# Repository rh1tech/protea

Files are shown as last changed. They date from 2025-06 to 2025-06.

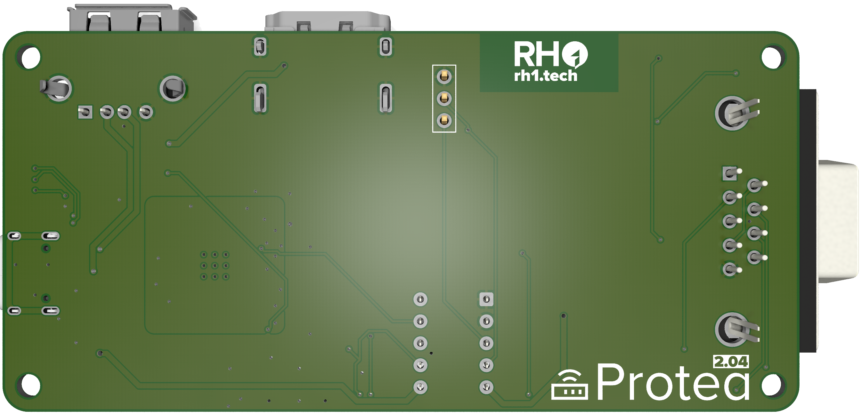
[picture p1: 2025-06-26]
DOCS/back.png

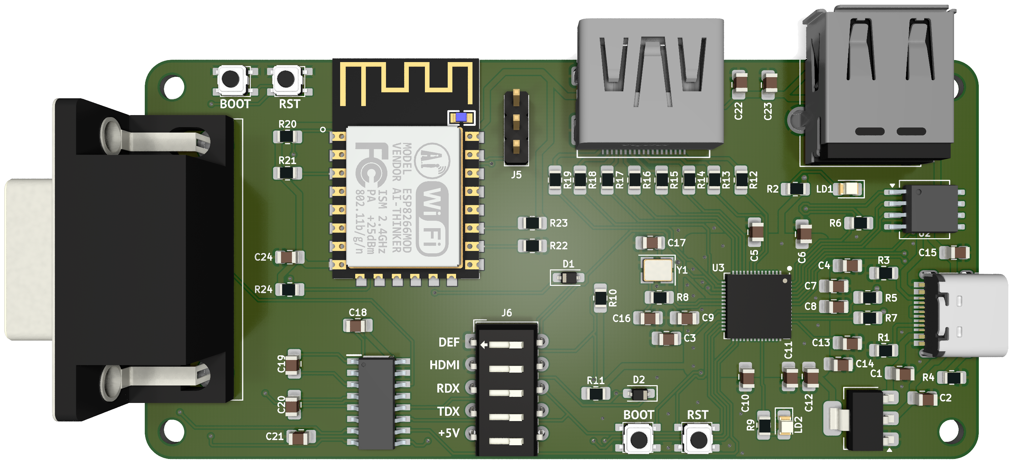
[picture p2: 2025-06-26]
DOCS/front.png

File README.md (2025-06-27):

# Protea

Protea is a custom development board designed in KiCad that bridges the gap between vintage computing and modern connectivity. Named after the protea flower, which itself derives from Proteus, son of Poseidon in Greek mythology, this board embodies the shape-shifting adaptability that made the mythological Proteus legendary. Just as the protea flower has survived and adapted for over 300 million years, becoming a symbol of longevity and endurance, the Protea development board is designed to endure and adapt across different technological eras.

The protea’s incredible diversity of forms - which inspired Carl Linnaeus to name it after the shape-shifting Proteus - mirrors this board’s versatility in connecting vintage computing with modern internet capabilities.

Documentation: [rh1.tech](https://rh1.tech/projects/protea)

## Hardware Specifications

### Primary Controller:

- RP2040 Microcontroller - directly soldered on board
- Dual-core ARM Cortex-M0+ processor running up to 133 MHz
- 264kB on-chip SRAM for program execution
- 8 Programmable I/O (PIO) state machines for custom peripheral support

### Connectivity Controller:
- ESP8266 Microcontroller - integrated Wi-Fi-to-Serial modem functionality
- 802.11 Wi-Fi support for internet connectivity
- AT command compatibility for seamless vintage computer integration

### Interface Ports:

- USB Port - keyboard input support with hub compatibility
- DB9 Serial Port - RS232 connectivity for vintage computers and external devices
- HDMI Port - native digital video output without conversion
- Power Input - USB-powered operation

## Firmware Ecosystem

Protea operates using two complementary firmware components:

### [Iris](https://github.com/rh1tech/iris) Terminal Software

- VT100/VT102 terminal emulation with full attribute support
- Instant-on operation with no boot time
- Configurable fonts and display settings
- PETSCII mode for Commodore compatibility

### [Hermes](https://github.com/rh1tech/hermes) Wi-Fi Modem

- Hayes-compatible AT command set
- Telnet protocol support for internet connectivity
- Transparent Wi-Fi-to-Serial bridge operation
- BBS and vintage online service access

## Use Cases

Protea enables seamless connection of classic computers to modern internet resources, providing access to text-mode BBS systems and online communities that maintain the spirit of early computing culture. The board serves as a bridge between RS232 devices and Wi-Fi networks, ensuring that vintage computing enthusiasts can maintain an authentic retro computing experience while leveraging contemporary internet connectivity.

The platform supports text-mode internet browsing for those who prefer minimalist computing approaches, while also serving as a foundation for terminal-based development environments. Protea is particularly well-suited for retrocomputing projects that require modern connectivity solutions, and functions as an educational platform for understanding the fundamentals of serial communications and terminal operations.

## Design Philosophy

Like the protea flower that has endured and adapted for over 300 million years, and the shape-shifting Proteus of Greek mythology, this development board embodies longevity, adaptability, and transformation. The board’s dual-microcontroller architecture ensures optimal performance for both local terminal processing and network communications, demonstrating the same versatility that characterizes its mythological and botanical namesakes.

The custom PCB design prioritizes signal integrity and reliable connectivity, making it suitable for both hobbyist projects and professional applications requiring robust serial terminal functionality.

## Getting Started

1.	Flash Firmware - Load [Iris](https://github.com/rh1tech/iris) onto the RP2040 and [Hermes](https://github.com/rh1tech/hermes) onto the ESP8266
2.	Connect Display - Attach HDMI monitor for terminal output
3.	Add Keyboard - Connect USB keyboard for input
4.	Configure Wi-Fi - Set up wireless connectivity through Hermes
5.	Connect Devices - Use DB9 port for vintage computer or RS232 device connections

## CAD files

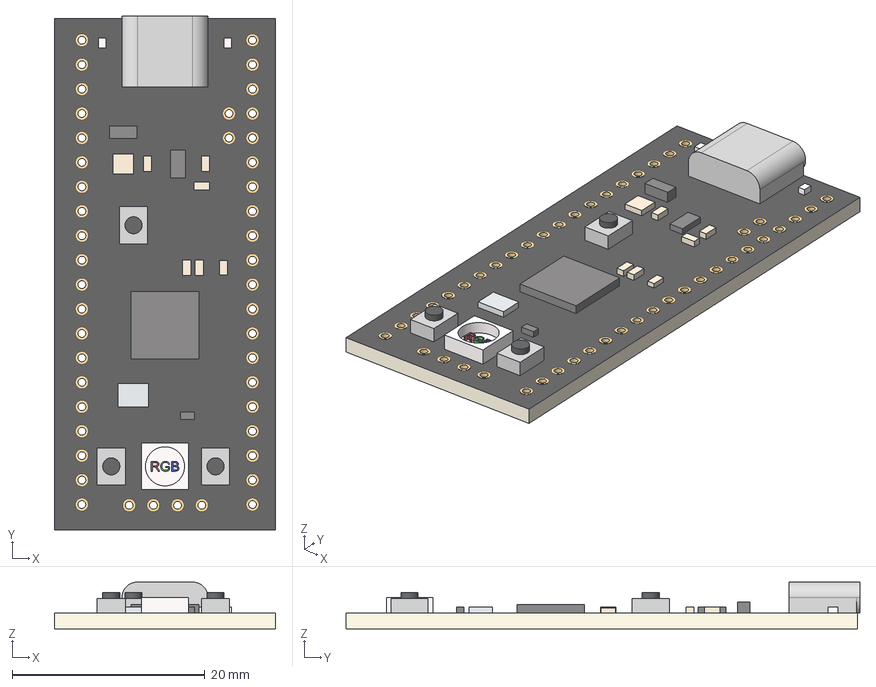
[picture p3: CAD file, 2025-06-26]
3D/PICO Clone-Black .step
22.9 x 53.3 x 4.88 mm

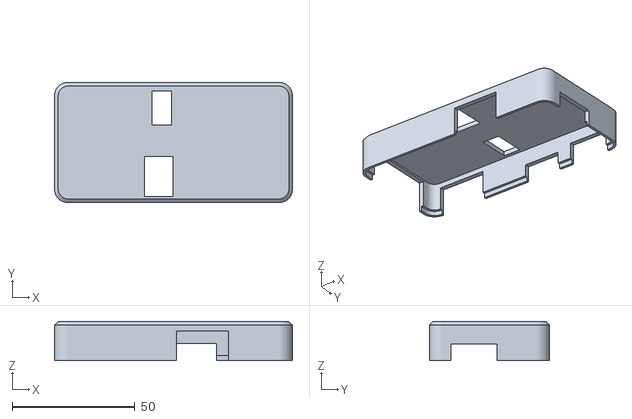
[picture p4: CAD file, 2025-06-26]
CASE/2_04/top.stl
97.0 x 49.0 x 16.0

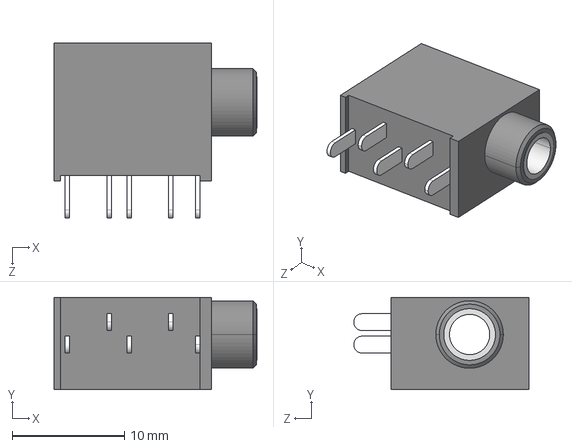
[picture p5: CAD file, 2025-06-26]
3D/SJ1-3535NG.stp
18.1 x 8.20 x 15.6 mm

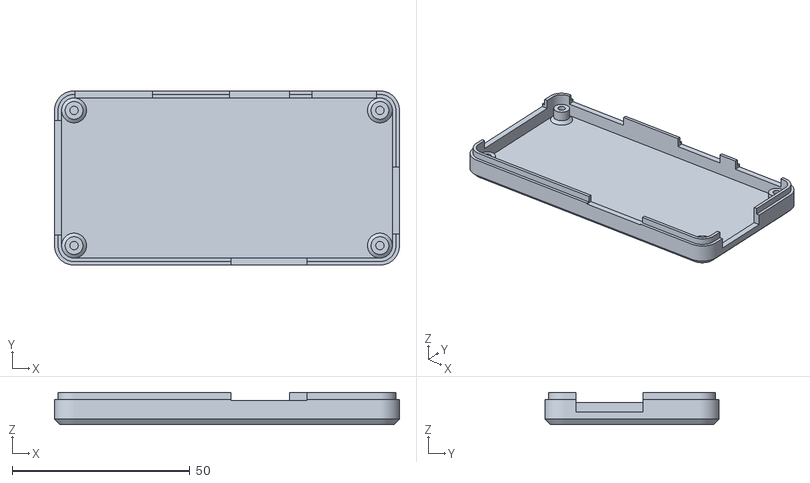
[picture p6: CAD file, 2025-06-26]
CASE/2_04/bottom.stl
97.0 x 49.0 x 9.00

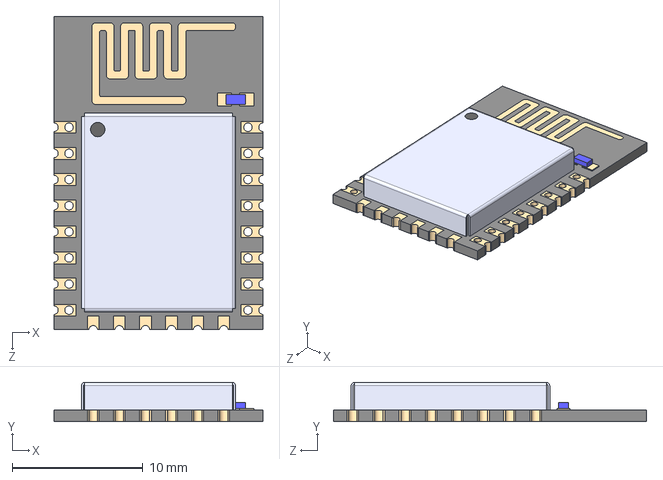
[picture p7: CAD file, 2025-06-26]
3D/ESP8266-12E_ESP-12E.step
16.0 x 3.00 x 24.0 mm

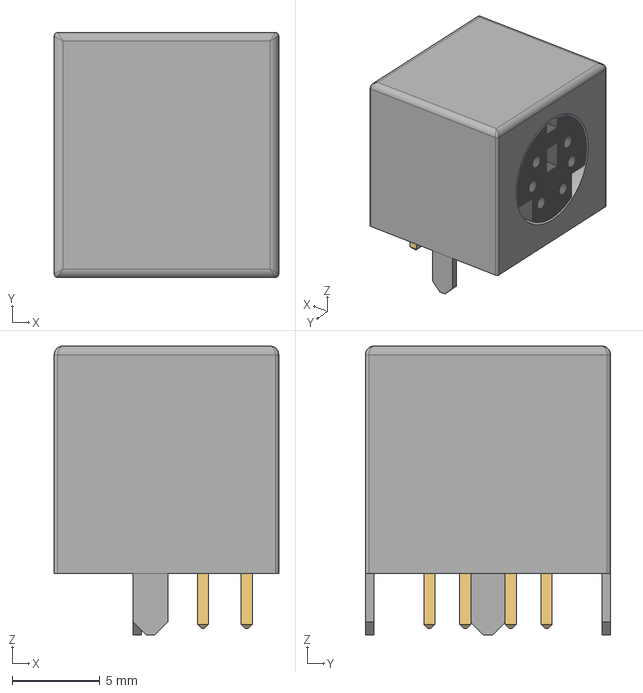
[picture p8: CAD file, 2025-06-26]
3D/Mini-DIN-6P.step
12.8 x 14.0 x 16.5 mm

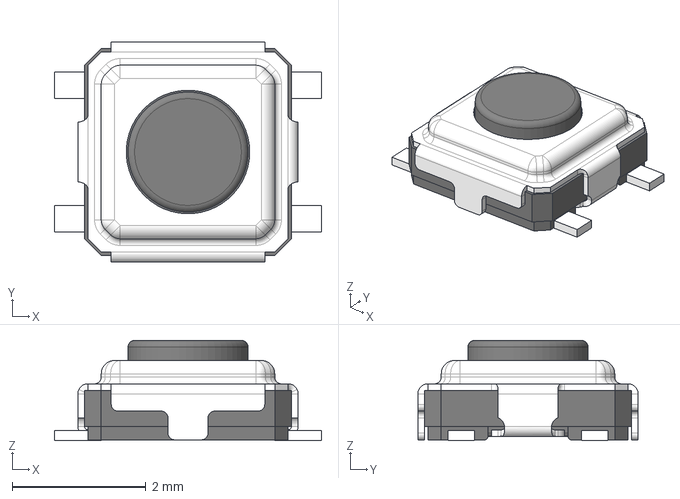
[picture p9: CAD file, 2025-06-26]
3D/Ts-1233_1.5.stp
4.00 x 3.30 x 1.50 mm

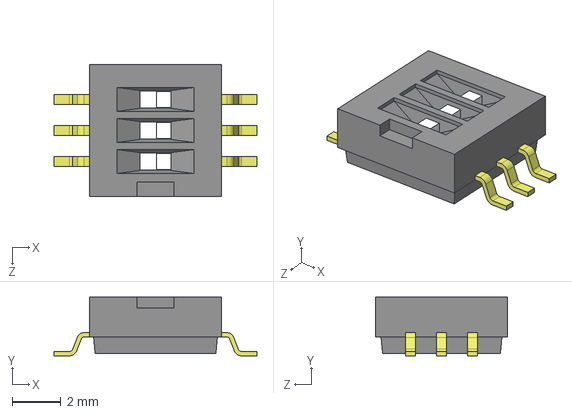
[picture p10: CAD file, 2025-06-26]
3D/DS05-127-2-03BK-SMT-TR.stp
8.30 x 2.40 x 5.38 mm

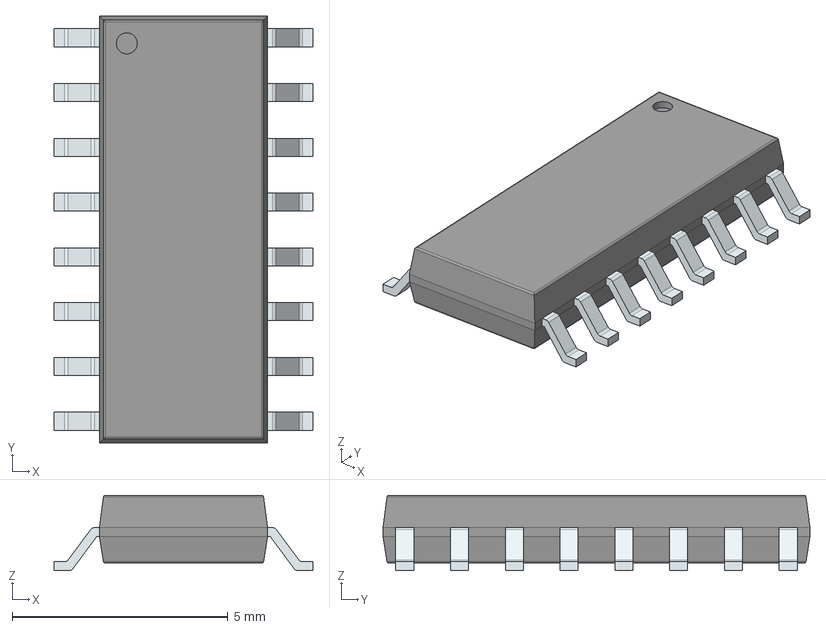
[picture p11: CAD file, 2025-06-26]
3D/MAX232CSE+.stp
6.00 x 9.90 x 1.75 mm
PinsArrayLR

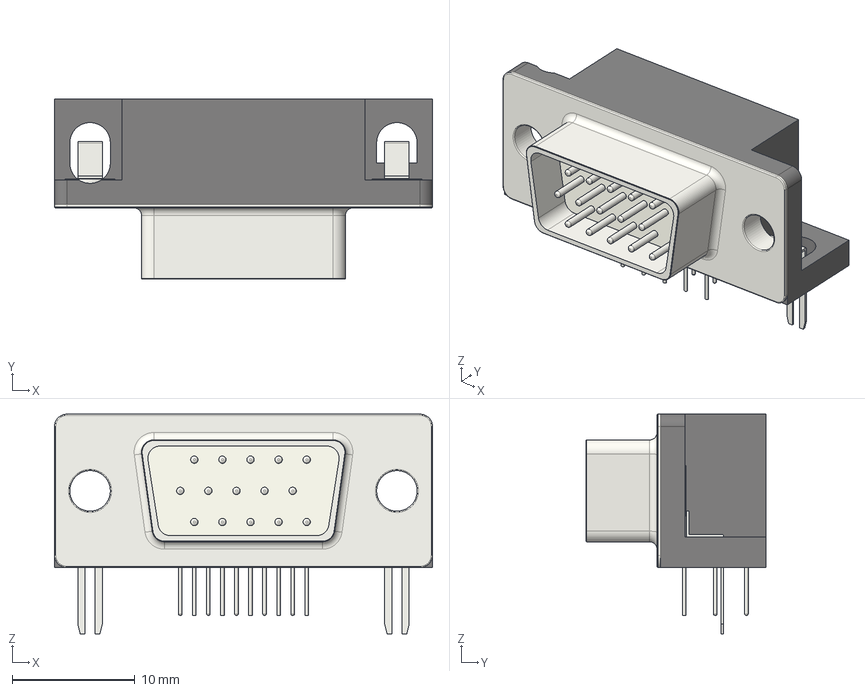
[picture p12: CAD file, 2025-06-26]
3D/DSUB-15-HD_Male_Horizontal_P2.29x1.98mm_EdgePinOffset3.03mm_Housed_MountingHolesOffset4.94mm.step
30.8 x 14.7 x 17.9 mm

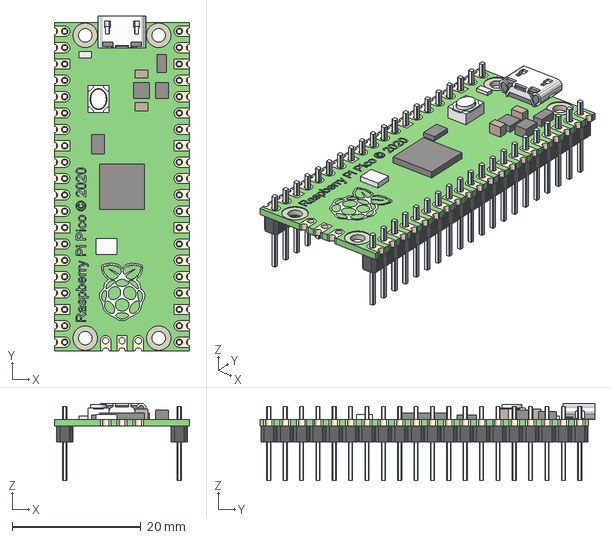
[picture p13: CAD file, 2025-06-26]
3D/raspberry pi pico with contacts.step
21.0 x 52.0 x 12.0 mm
ножка x 20
ножка v3(Mirror) x 20

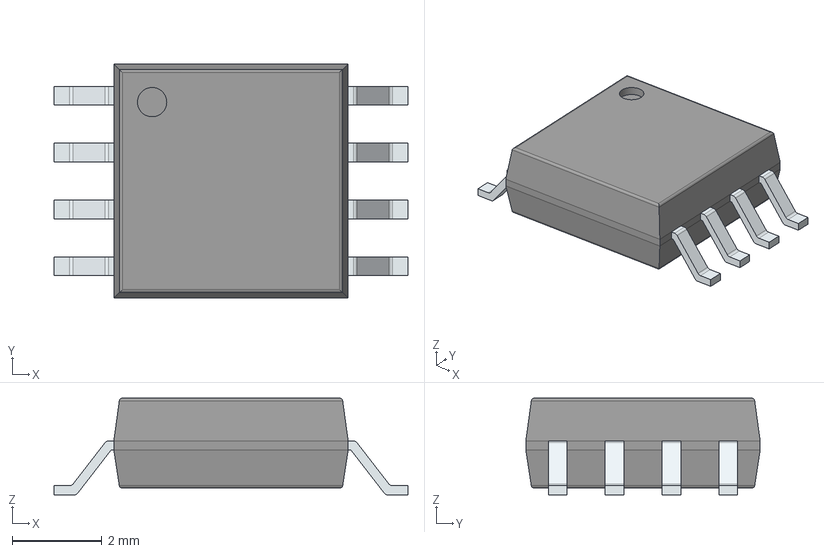
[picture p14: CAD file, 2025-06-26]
3D/W25Q128JVSIQ.stp
7.90 x 5.23 x 2.16 mm
PinsArrayLR

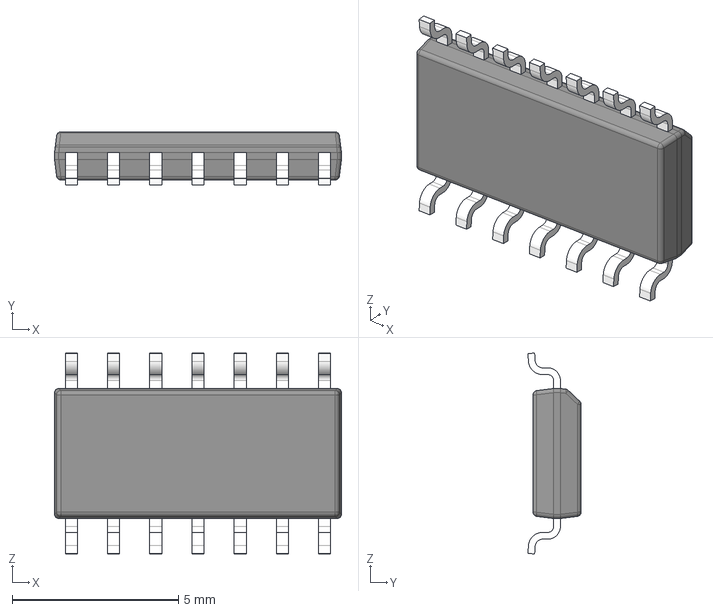
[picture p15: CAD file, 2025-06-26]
3D/soic-14.stp
8.64 x 1.60 x 6.05 mm
BODY_M14A_20
LEAD_M14A_46 x 14

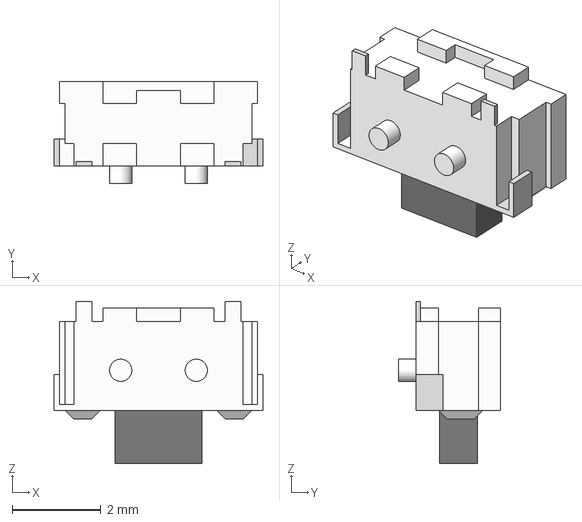
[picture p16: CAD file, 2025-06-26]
3D/1TS003B.step
4.70 x 2.30 x 3.65 mm

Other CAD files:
3D/PJ320D.STEP
3D/DSUB-9_Female_Horizontal_P2.77x2.84mm_EdgePinOffset9.90mm_Housed_MountingHolesOffset11.32mm.step
3D/SO-8_5.3x6.2mm_P1.27mm.step
3D/TS3USB221RSER.stp
3D/47571-0001.stp
3D/CUI_DEVICES_RCJ-013.step
3D/HRO_TYPE-C-31-M-12.step
3D/USB1035-GF-P-0-B-B.stp

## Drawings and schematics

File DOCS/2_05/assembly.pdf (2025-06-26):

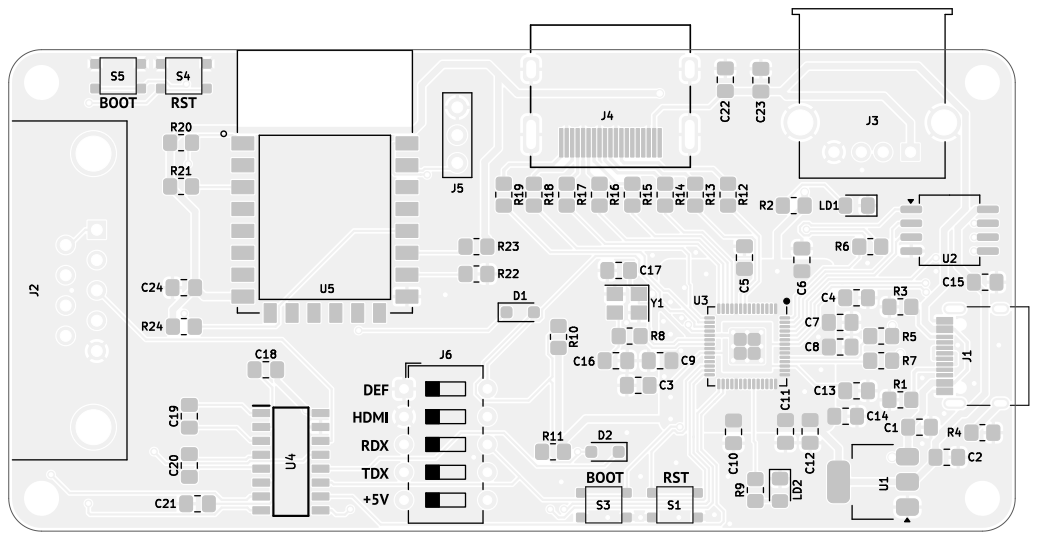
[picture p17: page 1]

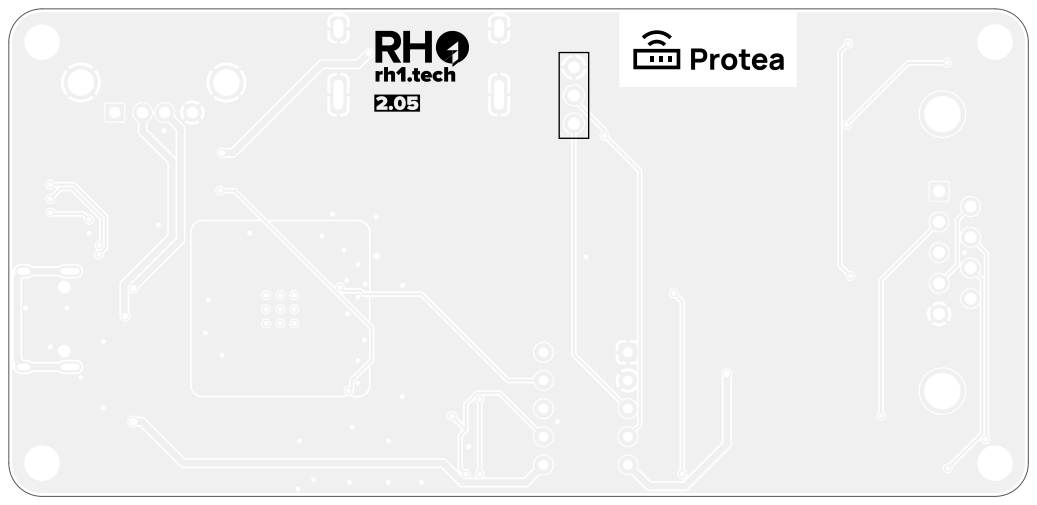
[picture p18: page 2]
D Date: 2025-04-21 KiCad; E.D.A. 9.0.0 Size: A4; Rev: 2.05; File: protea.kicad_pcb Sheet: Black; And; White; BOT Mikhail; Matveev; https://github.com/xtremespb/frank Black; BOT -; Page 2/4

Id: /1 Title: Protea

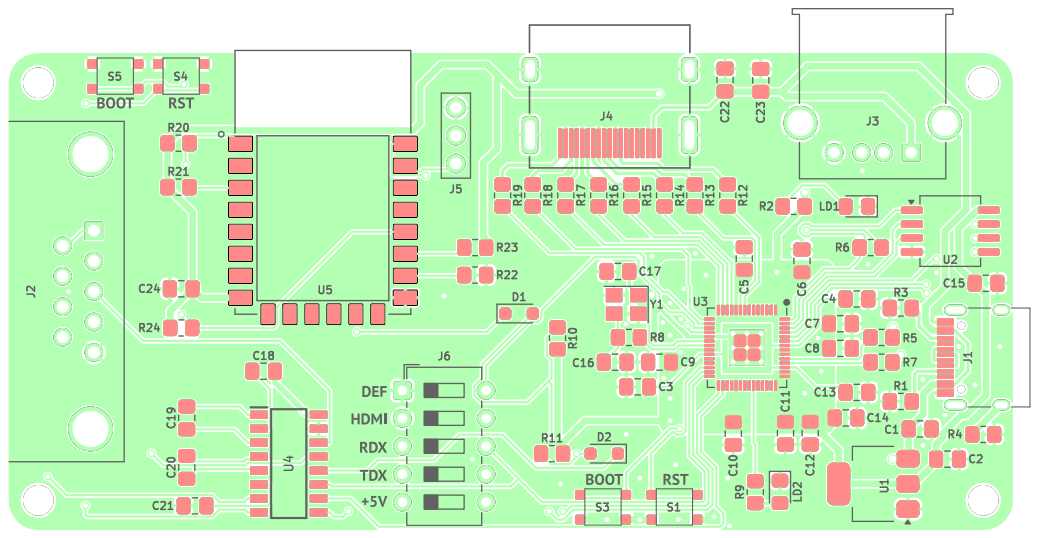
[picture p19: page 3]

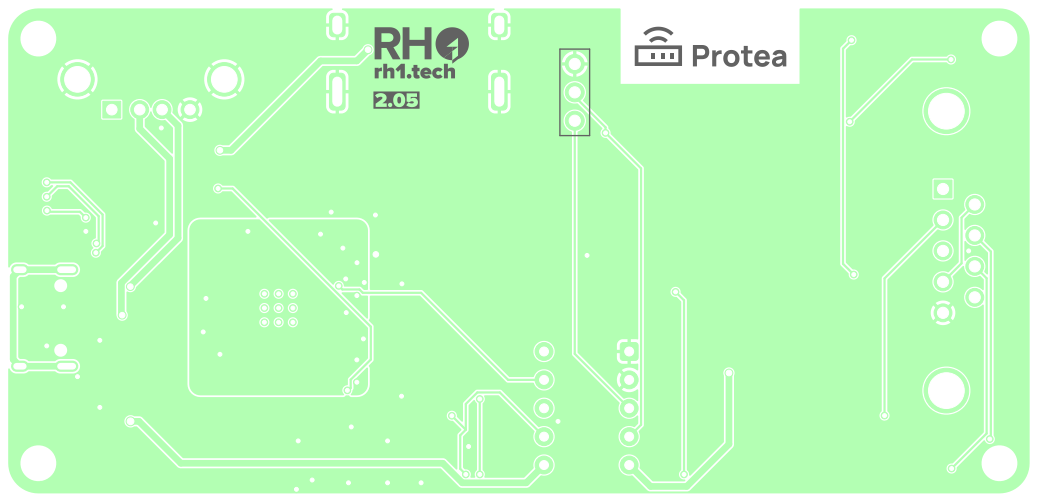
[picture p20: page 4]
D Date: 2025-04-21 KiCad; E.D.A. 9.0.0 Size: A4; Rev: 2.05; File: protea.kicad_pcb Sheet: Colored; BOT Mikhail; Matveev; https://github.com/xtremespb/frank Colored; BOT -; Page 4/4

Id: /1 Title: Protea

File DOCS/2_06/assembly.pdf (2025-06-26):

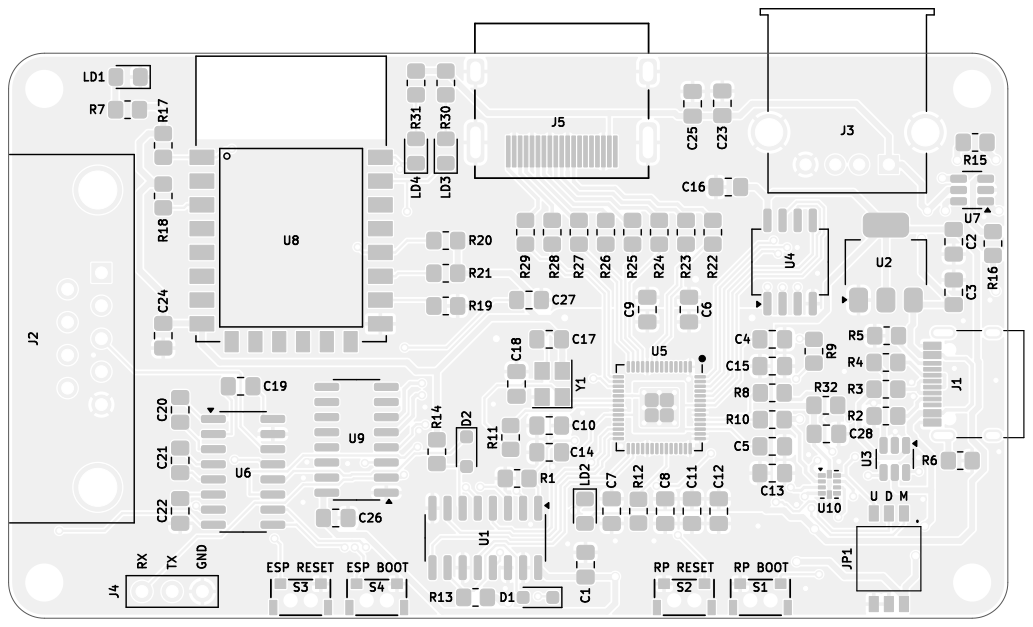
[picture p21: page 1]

https://github.com/xtremespb/frank Black And White TOP - Page 1/4

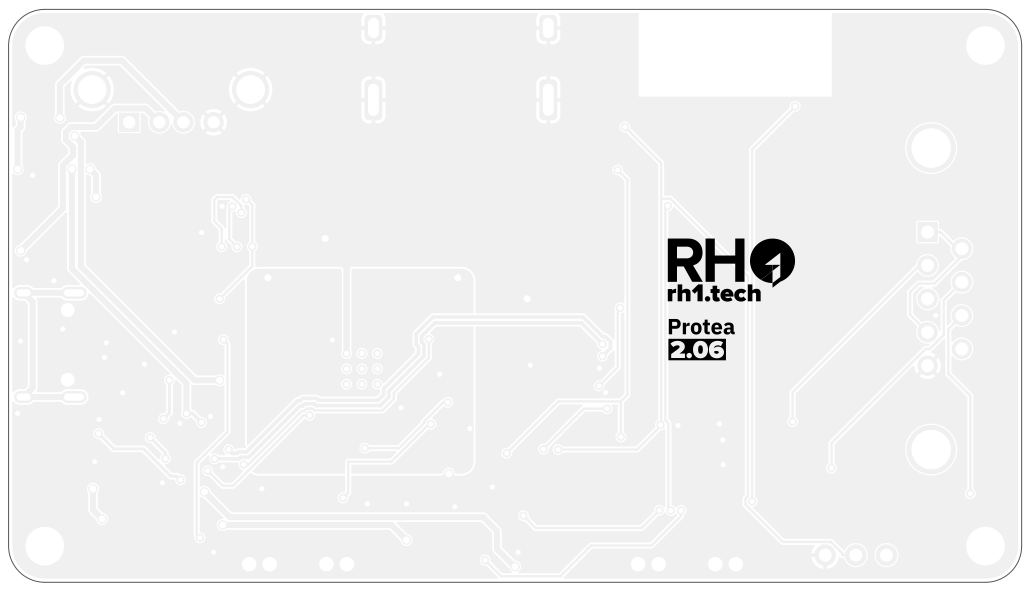
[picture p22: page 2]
D Date: 2025-04-21 KiCad; E.D.A. 9.0.0 Size: A4; Rev: 2.06; File: protea.kicad_pcb Sheet: Black; And; White; BOT Mikhail; Matveev; https://github.com/xtremespb/frank Black; BOT -; Page 2/4

Id: /1 Title: Protea

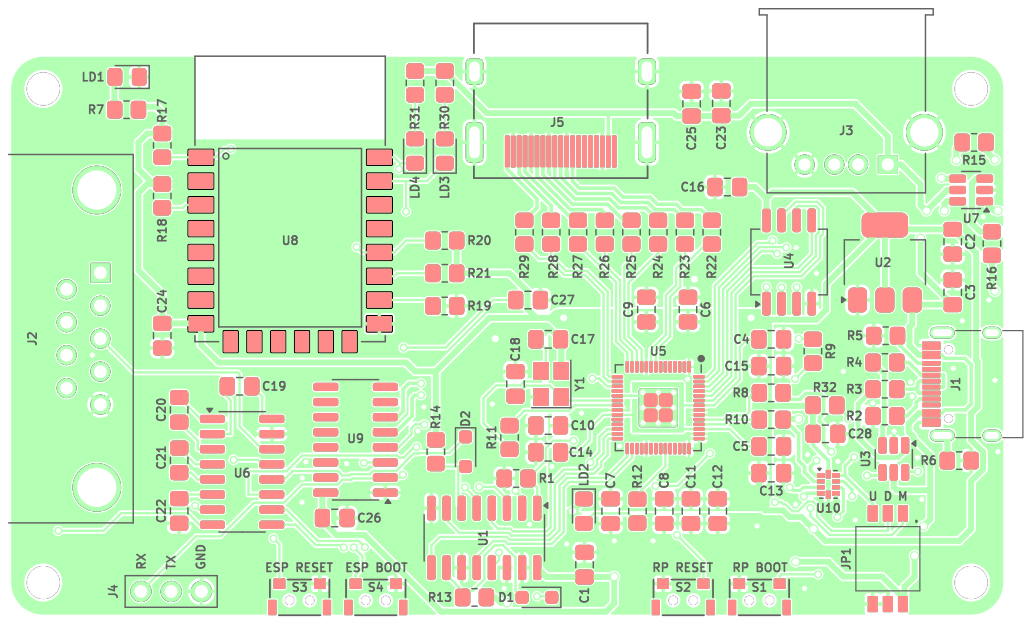
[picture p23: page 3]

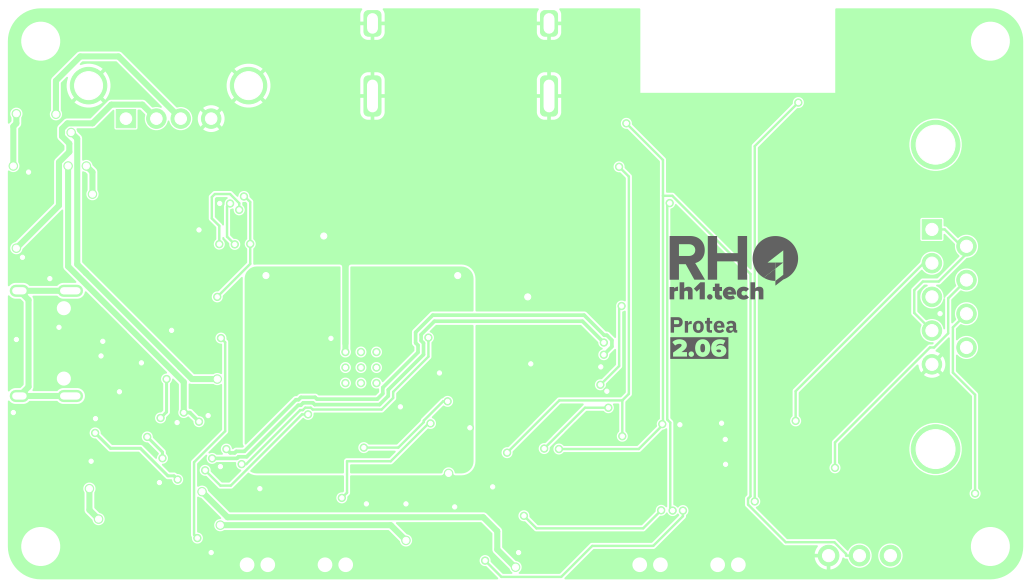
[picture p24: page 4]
D Date: 2025-04-21 KiCad; E.D.A. 9.0.0 Size: A4; Rev: 2.06; File: protea.kicad_pcb Sheet: Colored; BOT Mikhail; Matveev; https://github.com/xtremespb/frank Colored; BOT -; Page 4/4

Id: /1 Title: Protea

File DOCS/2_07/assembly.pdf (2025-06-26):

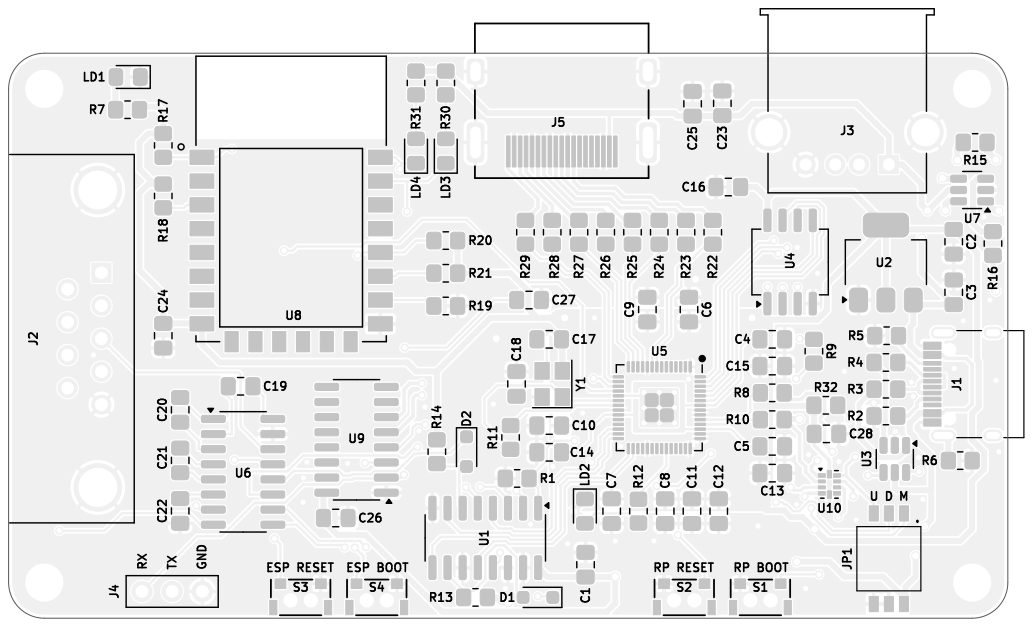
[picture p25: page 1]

https://github.com/xtremespb/frank Black And White TOP - Page 1/4

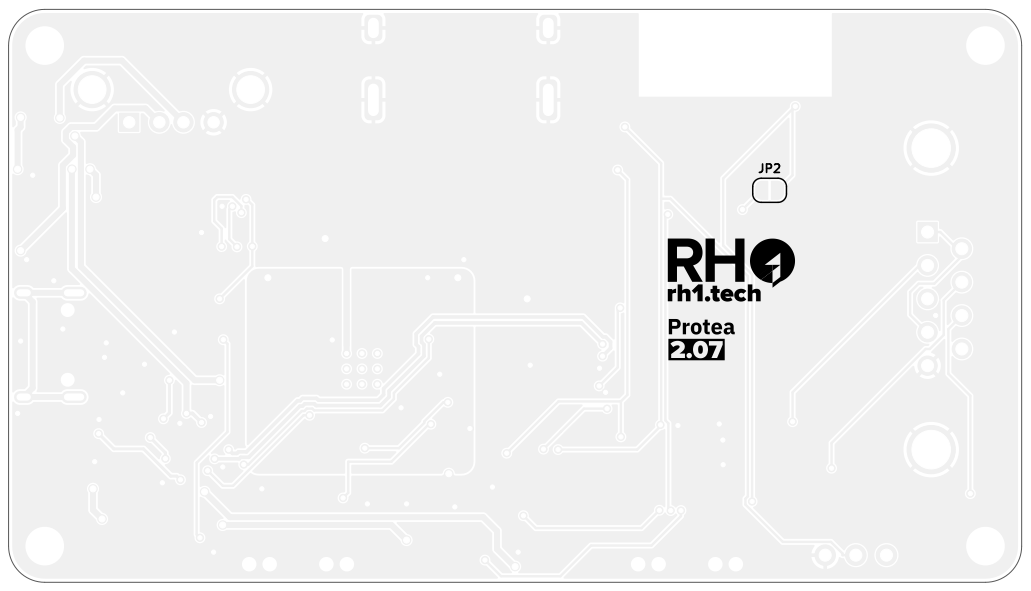
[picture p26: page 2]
D Date: 2025-06-22 KiCad; E.D.A. 9.0.0 Size: A4; Rev: 2.07; File: protea.kicad_pcb Sheet: Black; And; White; BOT Mikhail; Matveev; https://github.com/xtremespb/frank Black; BOT -; Page 2/4

Id: /1 Title: Protea

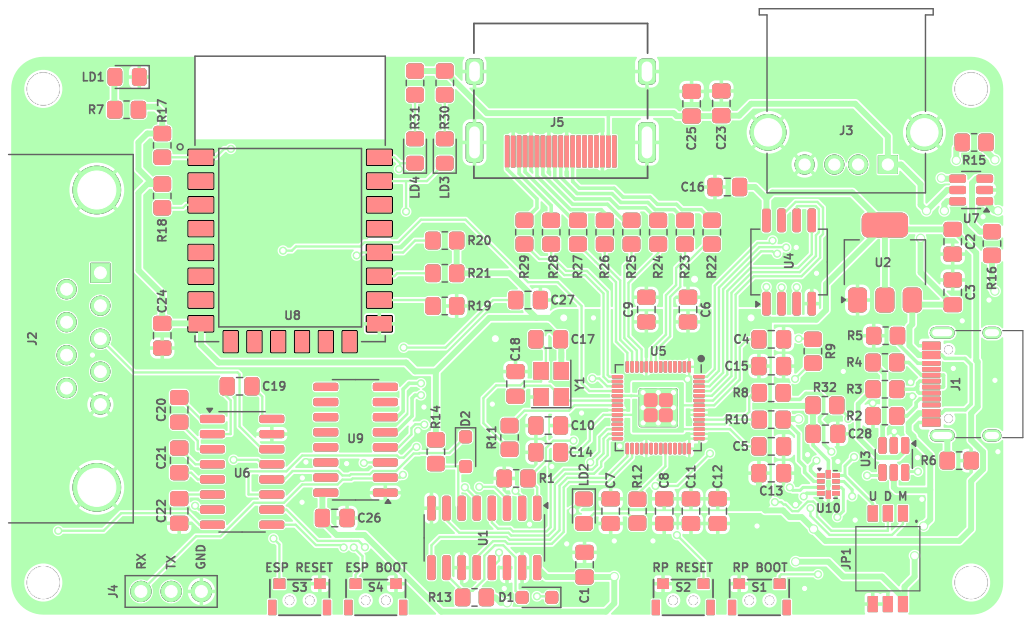
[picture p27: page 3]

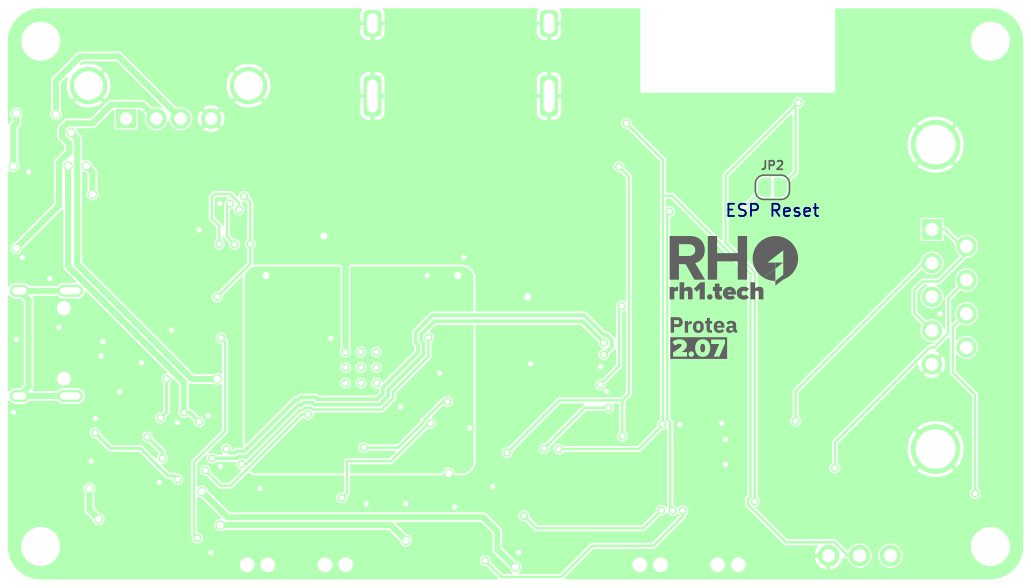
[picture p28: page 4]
D Date: 2025-06-22 KiCad; E.D.A. 9.0.0 Size: A4; Rev: 2.07; File: protea.kicad_pcb Sheet: Colored; BOT Mikhail; Matveev; https://github.com/xtremespb/frank Colored; BOT -; Page 4/4; ESP Reset

Id: /1 Title: Protea

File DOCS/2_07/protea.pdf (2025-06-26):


VBUS GND GND GND

ESP_CSO
GPIO4 GPIO5 GPIO9 GPIO10 GPIO12 GPIO13 GPIO14 GPIO16 MISO MOSI SCLK RXD


https://github.com/xtremespb/frank


4 U4 W25Q128JVSIQGND GND
~{CS} 1 CLK 6 DI(IO0) 5 DO(IO1) 2

https://github.com/xtremespb/frank


https://github.com/xtremespb/frank C20


https://github.com/xtremespb/frank


https://github.com/xtremespb/frank




https://github.com/xtremespb/frank GND

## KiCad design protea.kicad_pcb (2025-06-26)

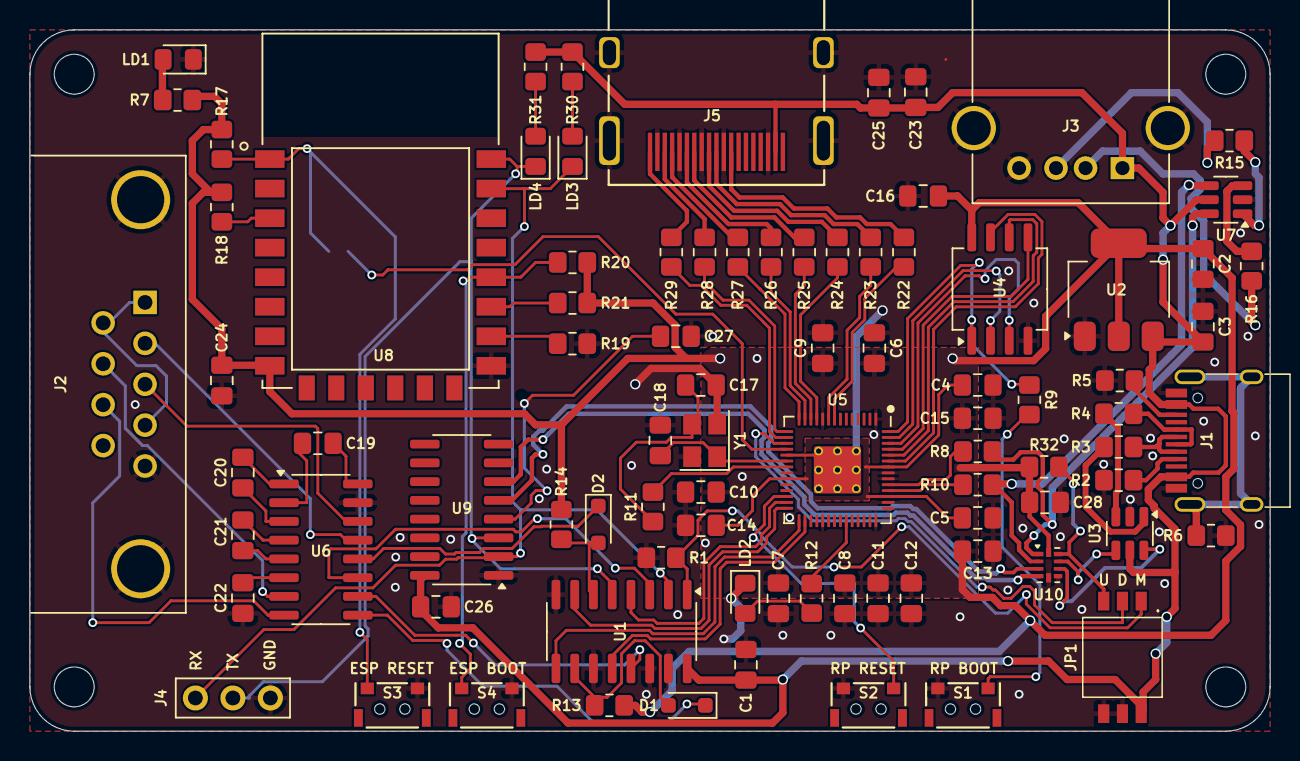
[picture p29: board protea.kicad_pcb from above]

Board: 2 copper layers, 84.0 x 47.5 mm, 92 parts (1 on the bottom side), 89 nets.

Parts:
C1, C4, C5, C6, C7, C8, C9, C10, C11, C12, C13, C16, C25, C26, C27, C28: 100n; Capacitor (0805)
C2, C3, C23: 10u; Capacitor (0805)
C14, C15, C19, C20, C21, C22, C24: 1u; Capacitor (0805)
C17, C18: 15p; Capacitor (0805)
D1, D2: 1N4148; Diode (SOD-323)
H1, H2, H3, H4: MountingHole; Mounting Hole (2.7mm)
J1: USB4215-03-A; USB Type C
J2: D-SUB 9 Male; D-SUB (9 pin, male, top mount)
J3: 676430910; USB Type A (single)
J4: ESP8266 Prog; Pin Header (1x03)
J5: HDMI Female; HDMI (female)
JP1: DS05-127-2-03BK-SMT-TR; DS05127203BKSMTTR
JP2: ESP Reset; Jumper (solder)
LD1: Green; LED (0805)
LD2: Blue; LED (0805)
LD3, LD4: Orange; LED (0805)
R1, R17, R18, R19, R20, R21, R32: 10K; Resistor (0805)
R2, R5: 5.1K; Resistor (0805)
R3, R4, R15, R16: 22R; Resistor (0805)
R6: 1M; Resistor (0805)
R7, R9, R11, R12, R13, R14: 1K; Resistor (0805)
R8, R10: 27R; Resistor (0805)
R22, R23, R24, R25, R26, R27, R28, R29: 270R; Resistor (0805)
R30, R31: 1.5K; Resistor (0805)
S1: Boot; TACT-SIDE-4623
S2, S3: Reset; TACT-SIDE-4623
S4: Flash; TACT-SIDE-4623
U1: SN74CBT3257CDR; SOP-16
U2: NCP1117 3.3; SOT-223
U3, U7: USBLC6-2SC6; SOT-23-6
U4: W25Q128JVSIQ; SOIC-8
U5: RP2040; QFN 56
U6: MAX232CSE+; SOP-16
U8: ESP8266 ESP-12F; ESP8266 ESP-12E
U9: CH340C; SOP-16
U10: TS3USB221RSER; UQFN-10
Y1: 12 MHz Passive; Crystal (3225)

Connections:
+3V3: C2.1, C6.1, C7.1, C8.1, C9.1, C10.1, C11.1, C12.1, C13.1, C15.1, C16.1, C24.1, C28.2, R7.2, R13.2, R14.2, R17.1, R18.1, R20.1, R21.1, R32.1, U2.2 (VO), U4.8 (VCC), U5.1 (IOVDD), U5.10 (IOVDD), U5.22 (IOVDD), U5.33 (IOVDD), U5.42 (IOVDD), U5.43 (ADC_AVDD), U5.44 (VREG_IN), U5.48 (USB_VDD), U5.49 (IOVDD), U8.8 (VCC), U10.10 (VCC)
/ESP_RESET: JP2.2 (B), R17.2, S3.2, U8.1 (RESET)
/ESP_RXD: J4.1, LD3.1 (K), U1.2 (1B1), U8.21 (RXD), U9.2 (TxD)
/ESP_TXD: J4.2, LD4.1 (K), U1.5 (2B1), U8.22 (TXD), U9.3 (RxD)
/GPIO6: R22.2, U5.8 (GPIO6)
/GPIO7: R23.2, U5.9 (GPIO7)
/GPIO8: R24.2, U5.11 (GPIO8)
/GPIO9: R25.2, U5.12 (GPIO9)
/GPIO10: R26.2, U5.13 (GPIO10)
/GPIO11: R27.2, U5.14 (GPIO11)
/GPIO12: R28.2, U5.15 (GPIO12)
/GPIO13: R29.2, U5.16 (GPIO13)
/GPIO14: JP1.2, U5.17 (GPIO14)
/GPIO15: JP2.1 (A), U5.18 (GPIO15)
/GPIO16: U1.4 (1A), U5.27 (GPIO16)
/GPIO17: U1.7 (2A), U5.28 (GPIO17)
/GPIO18: U1.9 (3A), U5.29 (GPIO18)
/GPIO19: U1.12 (4A), U5.30 (GPIO19)
/PW_D+: U3.4 (I/O2), U10.8 (D+)
/PW_D-: U3.6 (I/O1), U10.7 (D-)
/RP2040/GPIO25: R12.2, U5.37 (GPIO25)
/RP2040/QSPI_SCLK: U4.6 (CLK), U5.52 (QSPI_SCLK)
/RP2040/QSPI_SD0: U4.5 (DI(IO0)), U5.53 (QSPI_SD0)
/RP2040/QSPI_SD1: U4.2 (DO(IO1)), U5.55 (QSPI_SD1)
/RP2040/QSPI_SD2: U4.3 (IO2), U5.54 (QSPI_SD2)
/RP2040/QSPI_SD3: U4.7 (IO3), U5.51 (QSPI_SD3)
/RP2040/QSPI_SS: R9.1, U4.1 (~CS), U5.56 (QSPI_SS)
/RP2040/XIN: C18.1, U5.20 (XIN), Y1.1
/RP2040/XOUT: R11.1, U5.21 (XOUT)
/RP_D+: R8.1, U7.6 (I/O1), U10.1 (1D+)
/RP_D-: R10.1, U7.4 (I/O2), U10.2 (1D-)
/RS232/C1+: C20.2, U6.1 (C1+)
/RS232/C1-: C20.1, U6.3 (C1-)
/RS232/C2+: C21.2, U6.4 (C2+)
/RS232/C2-: C21.1, U6.5 (C2-)
/RS232/CTS_IN: J2.7, U6.7 (T2OUT)
/RS232/CTS_MAX: D1.1 (K), U6.9 (R2OUT)
/RS232/RTS_IN: J2.8, U6.8 (R2IN)
/RS232/RX_IN: J2.3, U6.14 (T1OUT)
/RS232/RX_MAX: D2.1 (K), U6.12 (R1OUT)
/RS232/TX_IN: J2.2, U6.13 (R1IN)
/RS232/V+: C19.1, U6.2 (V+)
/RS232/V-: C22.1, U6.6 (V-)
/RS232_CTS: D1.2 (A), R13.1, U1.10 (3B2)
/RS232_RTS: U1.13 (4B2), U6.10 (T2IN)
/RS232_RX: D2.2 (A), R14.1, U1.6 (2B2)
/RS232_TX: U1.3 (1B2), U6.11 (T1IN)
/RS232_VBUS: C19.2, U6.16 (VCC)
/RUN: S2.1, U5.26 (RUN)
/SN74_S: JP1.1, R1.2, U1.1 (S)
/USBMPXSW: JP1.3, R32.2, U10.9 (S)
/UT_D+: U9.5 (D+), U10.3 (2D+)
/UT_D-: U9.6 (D-), U10.4 (2D-)
GND: C1.1, C2.2, C3.2, C4.2, C5.2, C6.2, C7.2, C8.2, C9.2, C10.2, C11.2, C12.2, C13.2, C14.2, C15.2, C16.2, C17.2, C18.2, C22.2, C23.1, C24.2, C25.2, C26.2, C27.2, C28.1, J1.1 (GND), J1.12 (GND), J2.5, J3.4 (GND), J3.5 (Shield), J4.3, J5.2 (G_D2), J5.5 (G_D1), J5.8 (G_D0), J5.11 (G_CLK), J5.17 (G_DDC/CEC), J5.20 (SHIELD1), J5.21 (SHIELD2), J5.22 (SHIELD3), J5.23 (SHIELD4), JP1.4, JP1.5, LD1.1 (K), LD2.1 (K), R1.1, R2.1, R5.1, R6.2, R19.1, S1.2, S2.2, S3.1, S4.1, U1.8 (GND), U1.11 (3B1), U1.14 (4B1), U1.15 (~OE), U2.1 (GND), U3.2 (GND), U4.4 (GND), U5.19 (TESTEN), U5.57 (GND), U6.15 (GND), U7.2 (GND), U8.15 (GND), U9.1 (GND), U10.5 (GND), U10.6 (~OE), Y1.2, Y1.4
unnamed: C17.1, R11.2, Y1.3
unnamed: J1.4 (CC1), R2.2
unnamed: J1.10 (CC2), R5.2
unnamed: J1.5 (DN2), J1.7 (DN1), R3.2
unnamed: J1.6 (DP1), J1.8 (DP2), R4.2
unnamed: J1.13 (SHIELD), R6.1
unnamed: J2.1, J2.4, J2.6
unnamed: J3.3 (D+), R15.2
unnamed: J3.2 (D-), R16.2
unnamed: J5.12 (CLKN), R22.1
unnamed: J5.10 (CLKP), R23.1
unnamed: J5.9 (D0N), R24.1
unnamed: J5.7 (D0P), R25.1
unnamed: J5.6 (D1N), R26.1
unnamed: J5.4 (D1P), R27.1
unnamed: J5.3 (D2N), R28.1
unnamed: J5.1 (D2P), R29.1
unnamed: LD1.2 (A), R7.1
unnamed: LD2.2 (A), R12.1
unnamed: LD3.2 (A), R30.1
unnamed: LD4.2 (A), R31.2
unnamed: R3.1, U3.1 (I/O1)
unnamed: R4.1, U3.3 (I/O2)
unnamed: R9.2, S1.1
unnamed: R15.1, U7.1 (I/O1)
unnamed: R16.1, U7.3 (I/O2)
unnamed: R10.2, U5.46 (USB_DM)
unnamed: R8.2, U5.47 (USB_DP)
unnamed: C4.1, C5.1, C14.1, U5.23 (DVDD), U5.45 (VREG_VOUT), U5.50 (DVDD)
unnamed: R18.2, U8.3 (EN)
unnamed: R20.2, S4.2, U8.18 (IO0)
unnamed: R21.2, U8.17 (IO2)
unnamed: R19.2, U8.16 (IO15)
unnamed: C27.1, U9.4 (3V)
VBUS: C1.2, C3.1, C23.2, C25.1, C26.1, J1.2 (VBUS), J1.11 (VBUS), J3.1 (VBUS), J5.18 (+5V), JP1.6, R30.2, R31.1, U1.16 (VCC), U2.3 (VI), U3.5 (VBUS), U7.5 (VBUS), U9.16 (VCC)

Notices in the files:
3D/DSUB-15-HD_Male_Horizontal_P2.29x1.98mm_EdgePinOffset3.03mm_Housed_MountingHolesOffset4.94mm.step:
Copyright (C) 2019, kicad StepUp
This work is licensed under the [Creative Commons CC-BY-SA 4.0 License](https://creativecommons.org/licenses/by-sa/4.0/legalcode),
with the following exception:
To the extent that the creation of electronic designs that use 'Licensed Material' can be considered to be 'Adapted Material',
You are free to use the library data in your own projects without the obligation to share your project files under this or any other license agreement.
